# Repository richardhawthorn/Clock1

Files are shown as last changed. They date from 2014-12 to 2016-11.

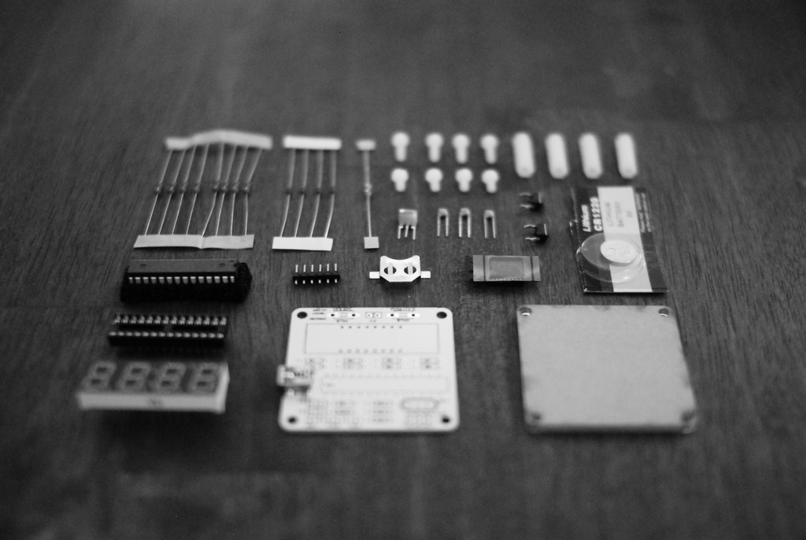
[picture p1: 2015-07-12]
images/parts1.jpg

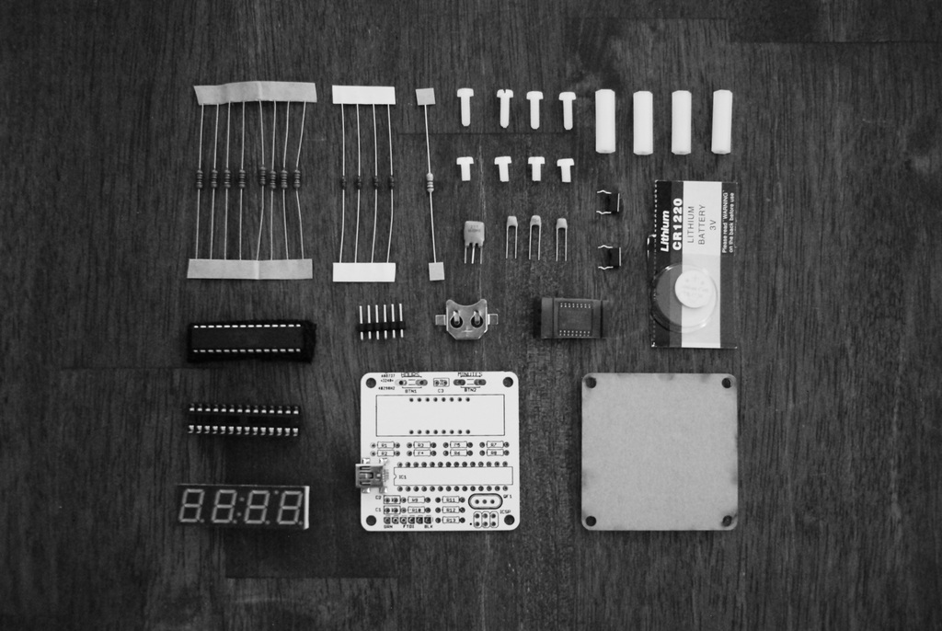
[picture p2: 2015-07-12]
images/parts2.jpg

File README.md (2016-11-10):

### Description

PCB and Arduino code for a basic clock

<div id="link">
	<a href="http://www.deluxecapacitor.com/projects/view/1">Project Page</a>
</div>

### Features

- 4 character 7-segment LED display
- ATMEGA328P with Arduino boot-loader
- 5V operation @ 16Mhz
- DS3231 battery backed clock
- 2x buttons to update minutes and seconds
- Mini USB power connector
- FTDI programming port
- ICSP port

#### Changes

Clock1.1 - First version
Clock1.2 - Replaced surface mount USB connector with through hole version

### License

This work is licensed under a Creative Commons Attribution-ShareAlike 4.0 International License.

<br />
Designed by <a xmlns:cc="http://creativecommons.org/ns#" href="http://www.richardhawthorn.com" property="cc:attributionName" rel="cc:attributionURL" target="_blank">Richard Hawthorn</a><br />
<a rel="license" href="http://creativecommons.org/licenses/by-sa/4.0/" target="_blank">View License</a>

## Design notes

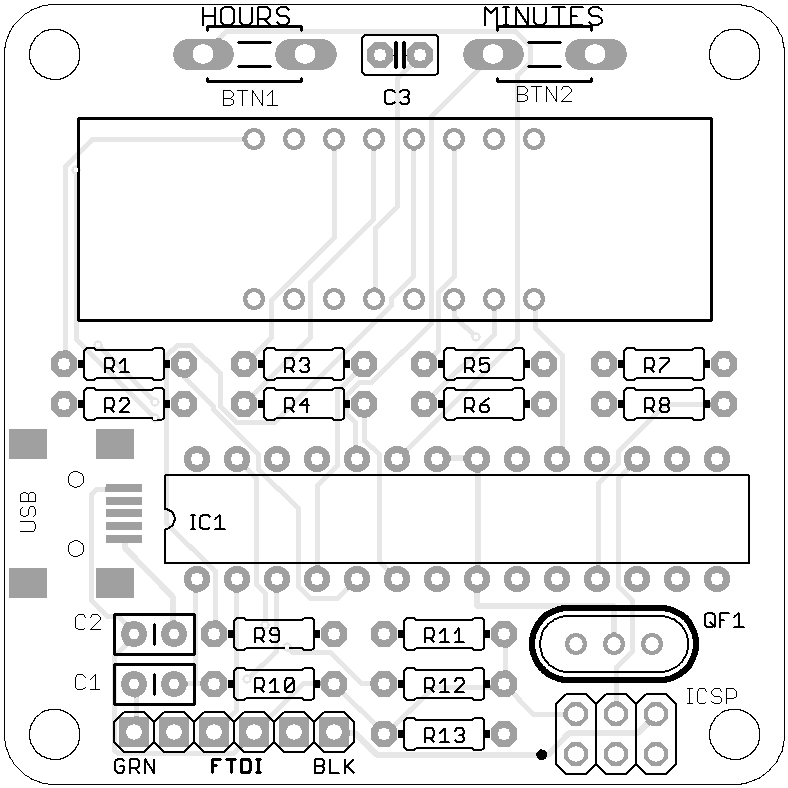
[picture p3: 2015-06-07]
images/pcb_front.png

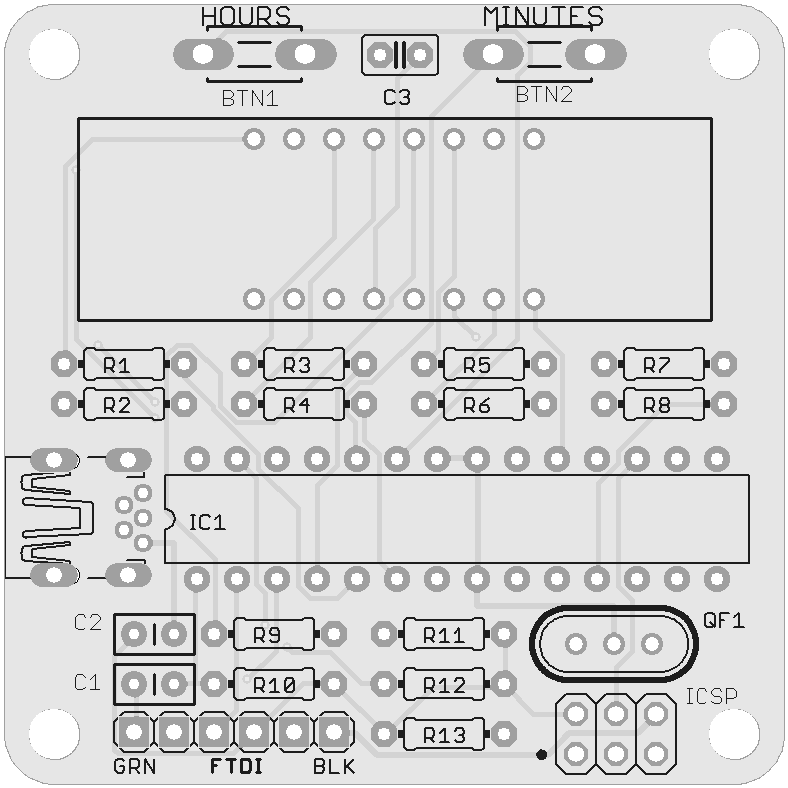
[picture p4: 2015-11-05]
images/pcb_front_1.2.png

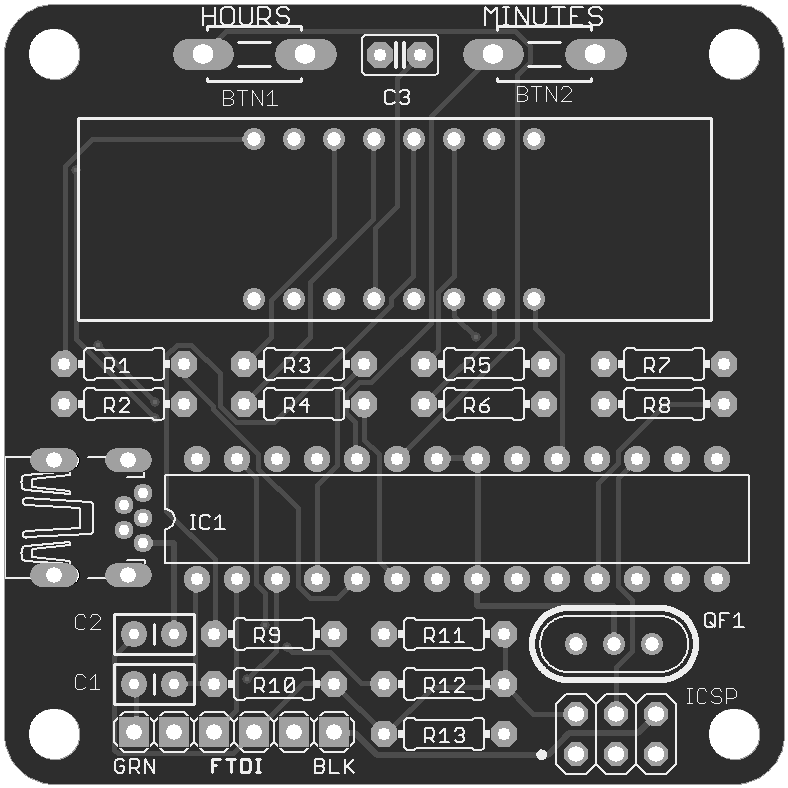
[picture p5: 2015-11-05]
images/pcb_front_1.2_black.png

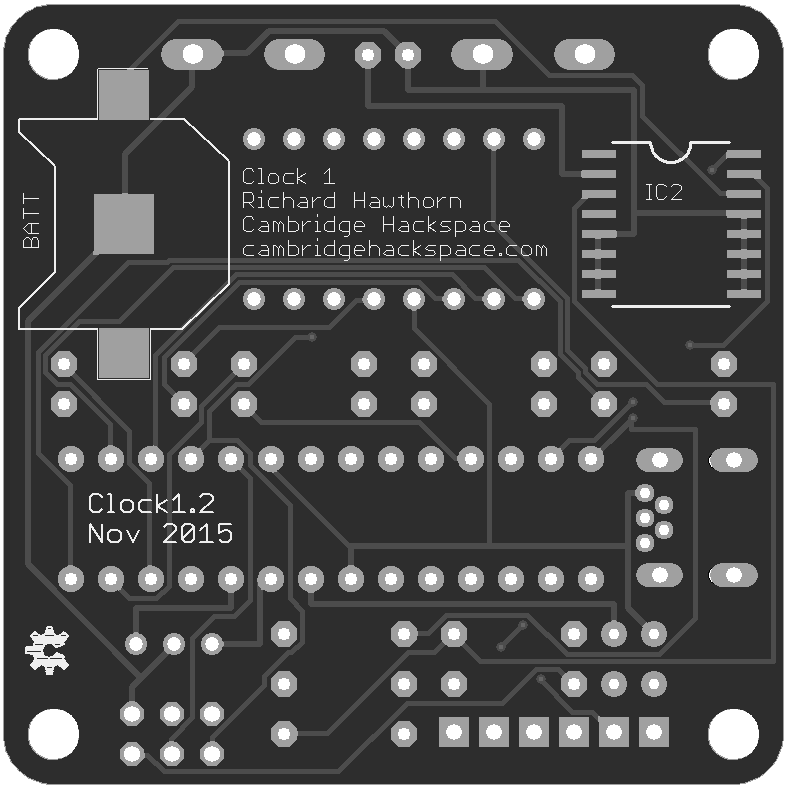
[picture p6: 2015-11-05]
images/pcb_back_1.2_black.png

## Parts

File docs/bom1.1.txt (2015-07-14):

### Part list

<pre>
Qty Value       Device          Parts
3   0.1uf       Capacitor       C1, C2, C3
4   10K         Resistor        R10, R11, R12, R13
1   680r        Resistor        R9
8   82r         Resistor        R1, R2, R3, R4, R5, R6, R7, R8
1   7SEG        7 Segment LED   LED1
1   8M10AHC49T  Crystal         QF1
1   ATMAGE328P  Processor       IC1
1   CR1220      Battery         BATT
1   DS3231      Calendar        IC2 
1   FTDI        Connector-1X6   CN4
1   ICSP        Connector-2X3   ICSP1   (No component needed)
1   HOURS       Button          BTN1
1   MINUTES     Button          BTN2
1   USB         Mini USB        CN1
</pre>

### Additional Hardware

1 x Battery  
1 x IC Socket  
1 x PCB  
1 x Front Plate  
4 x Pillars  
8 x Screws

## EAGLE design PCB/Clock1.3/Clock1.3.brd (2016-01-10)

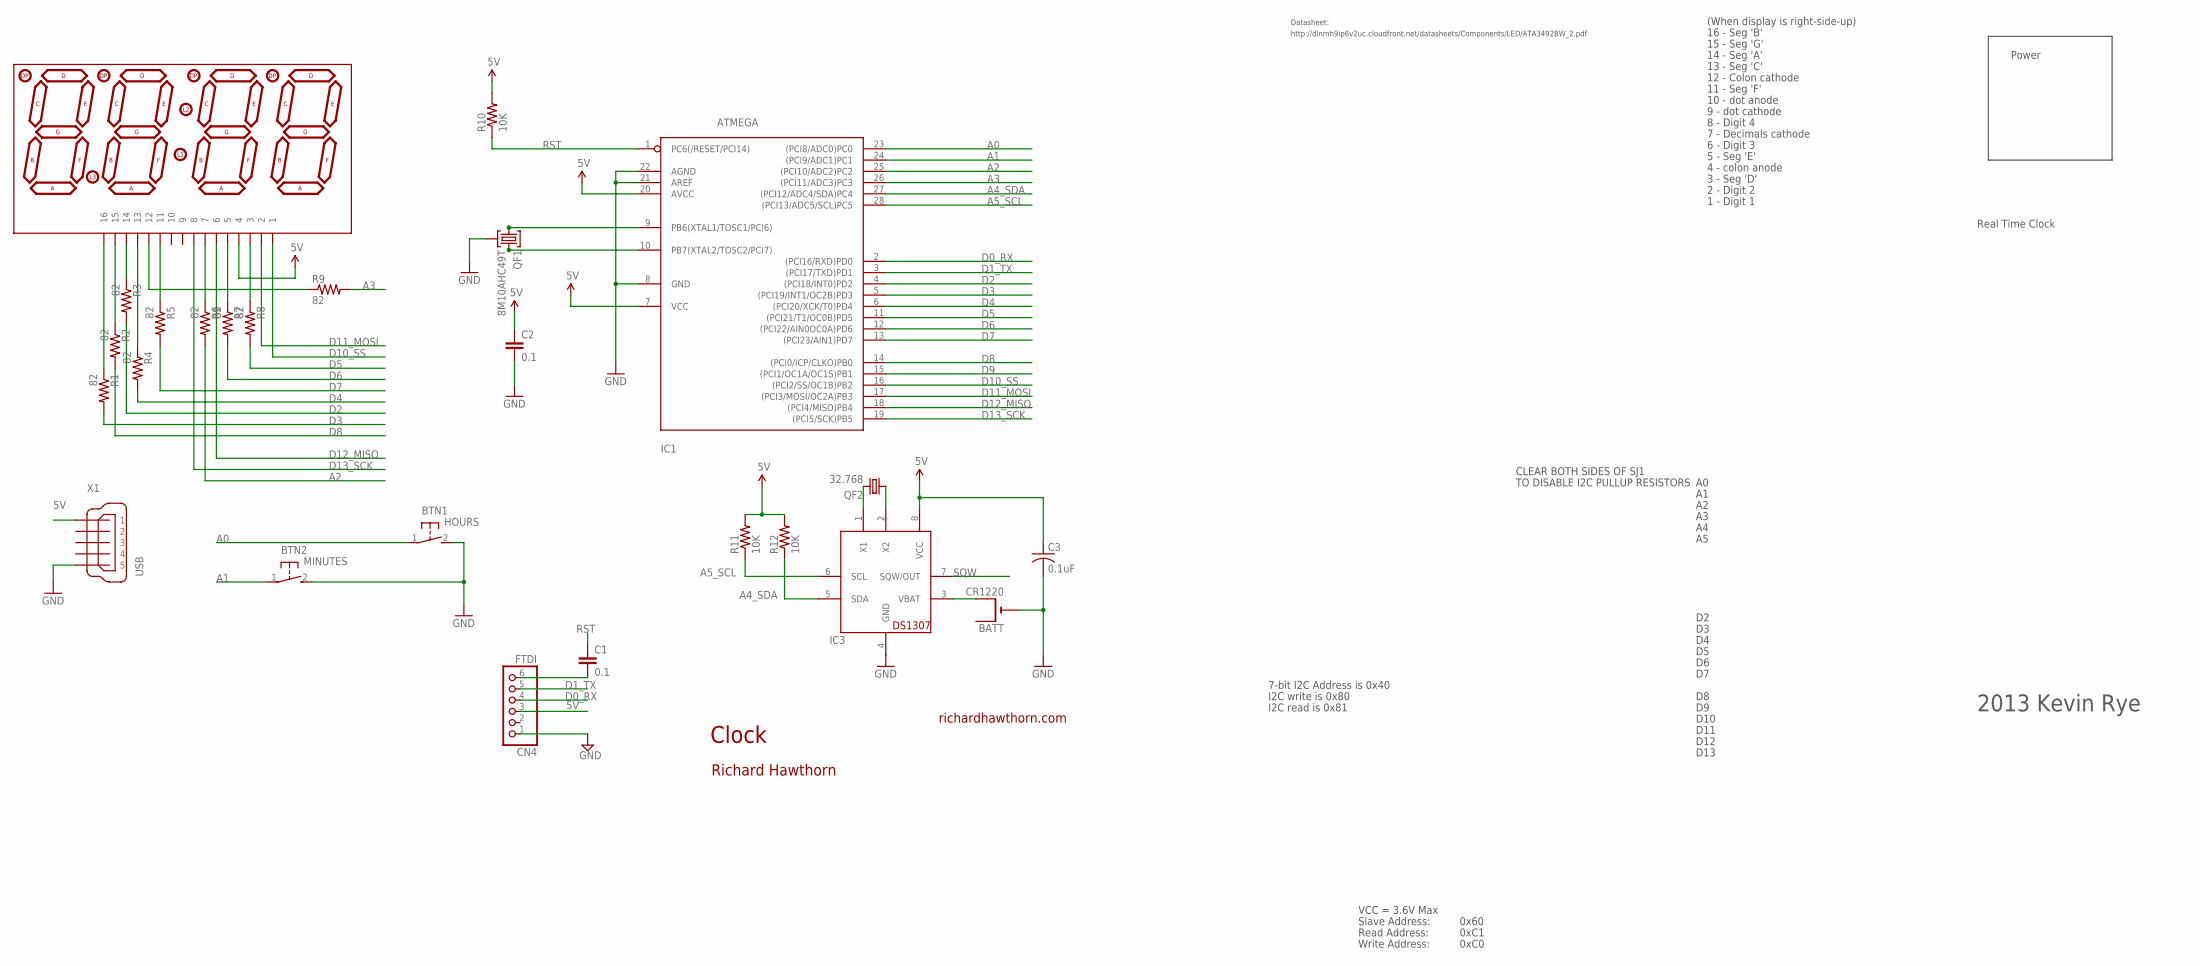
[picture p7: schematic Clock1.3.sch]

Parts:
BATT: CR1220; CR1220-SMD
BTN1: HOURS; DTS-3
BTN2: MINUTES; DTS-3
C1, C2: 0.1; CAP-PTH-SMALL2
C3: 0.1uF; C025-025X050
CN4: FTDI; 1X06
IC1: ATMEGA; DIL28-3-ROUND
IC3: DS1307; DIL08
LED1: 7SEG-4DIGIT; SPARKFUN_7-SEGMENT-4DIGIT
QF1: 8M10AHC49T; HC49U
QF2: 32.768; TC38H
R1, R2, R3, R4, R5, R6, R7, R8, R9: 82; 0204/7
R10, R11, R12: 10K; 0204/7
X1: USB; 32005-601

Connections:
5V: C2.1, C3.1, CN4.3, IC1.7 (VCC), IC1.20 (AVCC), IC3.8 (VCC), LED1.4, R10.2, R11.2, R12.2, X1.1
A0: BTN1.1, IC1.23 ((PCI8/ADC0)PC0)
A1: BTN2.1, IC1.24 ((PCI9/ADC1)PC1)
A2: IC1.25 ((PCI10/ADC2)PC2), R6.2
A3: IC1.26 ((PCI11/ADC3)PC3), R9.2
A4_SDA: IC1.27 ((PCI12/ADC4/SDA)PC4), IC3.5 (SDA), R12.1
A5_SCL: IC1.28 ((PCI13/ADC5/SCL)PC5), IC3.6 (SCL), R11.1
D0_RX: CN4.4, IC1.2 ((PCI16/RXD)PD0)
D1_TX: CN4.5, IC1.3 ((PCI17/TXD)PD1)
D2: IC1.4 ((PCI18/INT0)PD2), R3.2
D3: IC1.5 ((PCI19/INT1/OC2B)PD3), R1.2
D4: IC1.6 ((PCI20/XCK/T0)PD4), R4.2
D5: IC1.11 ((PCI21/T1/OC0B)PD5), R8.2
D6: IC1.12 ((PCI22/AIN0OC0A)PD6), R7.2
D7: IC1.13 ((PCI23/AIN1)PD7), R5.2
D8: IC1.14 ((PCI0/ICP/CLKO)PB0), R2.2
D9: IC1.15 ((PCI1/OC1A/OC1S)PB1)
D10_SS: IC1.16 ((PCI2/SS/OC1B)PB2), LED1.1
D11_MOSI: IC1.17 ((PCI3/MOSI/OC2A)PB3), LED1.2
D12_MISO: IC1.18 ((PCI4/MISO)PB4), LED1.6
D13_SCK: IC1.19 ((PCI5/SCK)PB5), LED1.8
GND: BATT.-, BTN1.2, BTN2.2, C2.2, C3.2, CN4.1, IC1.8 (GND), IC1.21 (AREF), IC1.22 (AGND), IC3.4 (GND), QF1.2, X1.5
unnamed: BATT.+$2 (+1), IC3.3 (VBAT)
unnamed: LED1.16, R1.1
unnamed: LED1.15, R2.1
unnamed: LED1.12, R9.1
unnamed: LED1.7, R6.1
unnamed: IC3.1 (X1), QF2.2
unnamed: IC3.2 (X2), QF2.1
unnamed: IC1.9 (PB6(XTAL1/TOSC1/PCI6)), QF1.1
unnamed: C1.2, CN4.6
unnamed: LED1.13, R4.1
unnamed: LED1.14, R3.1
unnamed: LED1.11, R5.1
unnamed: IC1.10 (PB7(XTAL2/TOSC2/PCI7)), QF1.3
unnamed: LED1.5, R7.1
unnamed: LED1.3, R8.1
RST: C1.1, IC1.1 (PC6(/RESET/PCI14)), R10.1
SQW: IC3.7 (SQW/OUT)

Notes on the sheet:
Clock
richardhawthorn.com
Richard Hawthorn
CLEAR BOTH SIDES OF SJ1
TO DISABLE I2C PULLUP RESISTORS
7-bit I2C Address is 0x40
I2C write is 0x80
I2C read is 0x81
VCC = 3.6V Max
Read Address:
Write Address:
Slave Address:
0x60
0xC1
0xC0
14 - Seg 'A'
13 - Seg 'C'
12 - Colon cathode
11 - Seg 'F'
10 - dot anode
9 - dot cathode
8 - Digit 4
7 - Decimals cathode
6 - Digit 3
5 - Seg 'E'
4 - colon anode
3 - Seg 'D'
2 - Digit 2
Real Time Clock
1 - Digit 1
15 - Seg 'G'
16 - Seg 'B'
D10
D11
D12
D13
http://dlnmh9ip6v2uc.cloudfront.net/datasheets/Components/LED/ATA3492BW_2.pdf
Datasheet:
Power
(When display is right-side-up)

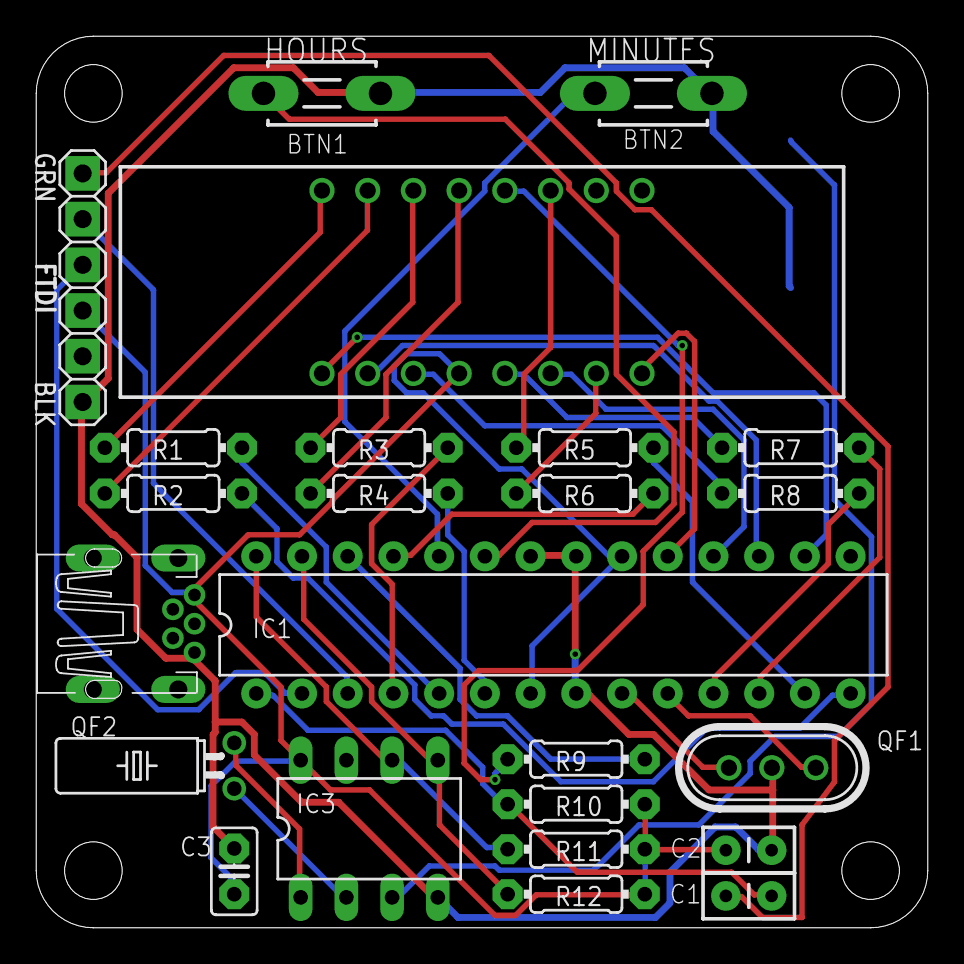
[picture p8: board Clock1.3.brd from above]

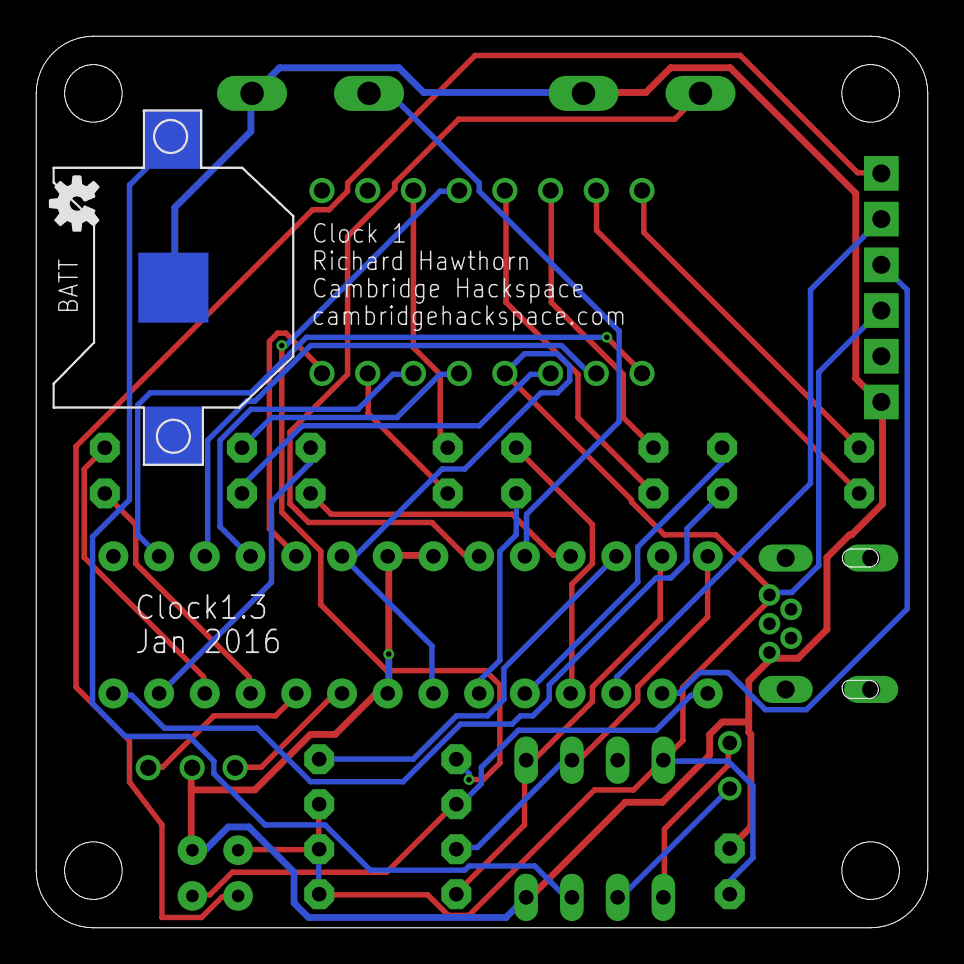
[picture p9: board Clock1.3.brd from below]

Board: 2 copper layers, 49.5 x 49.5 mm, 26 parts (2 on the bottom side), 37 nets.

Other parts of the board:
U$3: OSHW-LOGO-S

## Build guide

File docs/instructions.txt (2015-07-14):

### Instructions

#### Initial components

Lets start building!

- **Resistors:** there are 3 different types  
It doesn’t matter which way around these go.

    82r (grey red black)  
    Part: R1, R2, R3, R4, R5, R6, R7, R8   

    680r (blue grey brown)  
    Part: R9  

    10k (brown black black red)  
    Part: R10, R11, R12, R13    

- **USB connector**  
Part: USB  

- **Buttons**   
Part: BTN1, BTN2  

- **IC socket**  
Part: IC1  
Make sure to match up the notch in the socket with the notch mark on the PCB  
Don’t put in the Arduino chip yet, we’ll do that later.  

- **Capacitors**  
0.1uf  
Part: C1, C2, C3    

- **7 Segment LED**  
Make sure the decimal places are at the bottom  
Part: LED1  

- **Crystal**  
Part: QF1  

- **FTDI** (Programming connector)  
Part: CN4  

#### Testing

Now is a good time to test your soldering (before you have added your Arduino chip).
With your multimeter set to continuity mode, test to make sure you don’t have a short on the power line. Try testing the processor pins 7 and 8, they should not be connected.

If you have a short here, or any other unexpected result during this build you will need to investigate further.  Check your soldering to make sure pins are not shorted together, make sure all solder joins are clean.

Plug in your usb cable, and check the power on the board, do you get 5v between pins 7 and 8 on the processor?

If you read anything less than 5v, unplug immediately.

If that all looks good then we can add in our Arduino chip (Unplug the USB power connector before proceeding). 

Remember to make sure the notch on the end of the processor matches up with the notch on the socket.

#### Final components
- **CR1220 Battery clip**  
Part: BATT   

- **Calendar Chip** - DS3231  
Part: IC2  

Soldering this part requires a steady hand, as it is a surface mount part.  Start by soldering 2 opposite pins of the device, making sure the notch on the chip matches up with the notch on the PCB.

Once you have 2 pins soldered, add some flux to the pins on one side of the chip.  Add solder to the tip of your iron, and touch it on each pin individually.  Do this with every pin on the first side of the chip. Make sure all pins are properly soldered before proceeding, this may mean repeating the soldering as above.

Repeat on the other side of the chip until all pins are soldered.

Note: no component is needed for the ICSP1 connector

#### Final testing

Re-check your soldering by putting the multimeter back into continuity mode, and checking pins 7 and 8 of the processor again.  These should not be shorted.

Power up the board and make sure you get 5v between pins 7 and 8.

If you read anything less than 5v, unplug immediately. 

Investigate your soldering if you see unexpected results.

#### Programming

You are now ready to program your device, grab an FTDI programmer, your usb cable and your laptop.  

Make sure you have downloaded the Arduino IDE from arduino.cc

You will also need the RTC library, follow their install instructions to get the library setup. Details here:
https://github.com/adafruit/RTClib

You may need to restart the Arduino IDE before proceeding

You can now download the clock software here: https://github.com/richardhawthorn/Clock1

When programming set the device as “Arduino UNO” 

#### Front plate

Once you have the software working you can add the front plate.

Remove the plastic from the perspex front plate, and screw it to the pillars.  This can then be attached to the pcbs using the remains screws.

#### Finished!

Da-da! You’ve built yourself an Arduino Clock.  Congratulations!

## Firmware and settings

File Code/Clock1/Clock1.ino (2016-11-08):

//   Clock1.1
//   Richard Hawthorn
//   Cambridge Hackspace
//   Based on code from Kevin Rye
//   2015-05-15
//
//   7 segment led pixels
//
//    _____         __A__
//   |     |       F     B
//   |_____|  -->  |--G--|
//   |     |       E     C
//   |_____|       |__D__|
//
//   Characters
//    _____     _____     _____     _____ 
//   |     |   |     | . |     |   |     |
//   |_____|   |_____|   |_____|   |_____|
//   |     |   |     | . |     |   |     |
//   |_____| o |_____| o |_____| o |_____| o
//      1         2         3         4
//

//includes
#include <Wire.h>
#include <RTClib.h>
RTC_DS1307 RTC;

//define time variables
int hours; //24 hour time
int hh; //12 hour
int mm;
int ss;
int timecc;

//how long to pause between each character
int displayPause = 1;

//define Pins
int segmentD = 5;
int segmentE = 6;
int segmentF = 7;
int segmentA = 2;
int segmentB = 3;
int segmentC = 4;
int segmentG = 8;
int ampm = 9;
int digitOne = 10;
int digitTwo = 11;
int digitThree = 12;
int digitFour = 13;
int hoursButton = A0;
int minsButton = A1;
int decimal = A2;

//colon pin used for clock2.1 variant
int colon = A3;
boolean colonState = false;
long colonCounter = 0;

//setup
void setup() {

  //pin modes
  pinMode(segmentA, OUTPUT);
  pinMode(segmentB, OUTPUT);
  pinMode(segmentC, OUTPUT);
  pinMode(segmentD, OUTPUT);
  pinMode(segmentE, OUTPUT);
  pinMode(segmentF, OUTPUT);
  pinMode(segmentG, OUTPUT);
  pinMode(digitOne, OUTPUT);
  pinMode(decimal, OUTPUT);
  pinMode(digitTwo, OUTPUT);
  pinMode(digitThree, OUTPUT);
  pinMode(digitFour, OUTPUT);
  pinMode(colon, OUTPUT);
  
  //buttons (with pullups)
  pinMode(hoursButton, INPUT_PULLUP);
  pinMode(minsButton, INPUT_PULLUP);
  
  //setup serial line for debugging
  Serial.begin(9600);
  
  //start the i2c and clock
  Wire.begin();
  RTC.begin();  

  if (! RTC.isrunning()) {
    Serial.println("Clock is not running!");
  }
  
  //flash the colon at 1hz
  flashColon();
  
}





//format and display the time
void displayTime(){
  timecc = hh*100+mm;
  showNum(timecc);
}

//get the current time and perform basic checks
void getTime(){
  
  DateTime now = RTC.now(); //time from the clock in 24 hour mode
  hh = hours = now.hour(); //used to check AM/PM status
  mm = now.minute();
  ss = now.second(); 
  
   //Basic time check
  if (hours > 24){
    hours = 0;
  } 
  
  if (mm >= 60){
    mm = 0;
  } 
  
}

//convert the time to 12 hour format
void convert12h(){
  
  if (hours < 1) {
    hh = 12;
  }

  if ((hours > 12) && (hours < 24)) {
    hh = hours - 12;
  }
  
}

//check the buttons, do we need to update the time
void checkButtons(){
  
   //hours button pressed
  if (digitalRead(hoursButton) == LOW) {
    //basic debounce
    delay(200);
    hours++;

    if (hours > 23) {
      hours = 0;
    }
    
    updateRTC();

  } 

  //minutes button pressed
  if (digitalRead(minsButton) == LOW) {
    //basic debounce
    delay(200);

    mm++;
    ss = 0;

    if (mm >59) {
      mm = 0;
    }
    
    updateRTC();

  }
  
}

//display the time
void showNum(int n) {

  //display digit X
  //digit 1 - only display if time is greater thatn 9:59
  int n1 = (n%10000)/1000;
  if (n > 999) {
    printNumber(n1,1);
  }
  delay(displayPause);
  resetNumbers();

  //digit 2
  int n2 = (n%1000)/100;
  printNumber(n2,2); 
  delay(displayPause);
  resetNumbers();

  //digit 3
  int n3 = (n%100)/10;
  printNumber(n3,3);
  delay(displayPause);
  resetNumbers();

  //digit 4
  int n4 = n%10;
  printNumber(n4,4); 
  delay(displayPause);
  resetNumbers();

}

//reset the screen, so everything is off
void resetNumbers(){
  
    digitalWrite(digitOne,LOW);
    digitalWrite(digitTwo,LOW);
    digitalWrite(digitThree,LOW);
    digitalWrite(digitFour,LOW);
    digitalWrite(decimal,HIGH); //decimal off
    digitalWrite(segmentA,HIGH);
    digitalWrite(segmentB,HIGH);
    digitalWrite(segmentC,HIGH);
    digitalWrite(segmentD,HIGH);
    digitalWrite(segmentE,HIGH);
    digitalWrite(segmentF,HIGH);
    digitalWrite(segmentG,HIGH);  
  
}

//output a specific number in a specific position
//n = number, d = position
void printNumber(int n, int d) {
 
  if ((n > 9) || (n < 0)){
    return;  
  }
  
  if ((d > 4) || (d < 1)){
    return;  
  }
  
  //d is the display to illuminate
  if(d==1)  {
    digitalWrite(digitOne,HIGH);
    digitalWrite(digitTwo,LOW);
    digitalWrite(digitThree,LOW);
    digitalWrite(digitFour,LOW);
    digitalWrite(decimal,HIGH); //decimal off
  } 

  if(d==2) {
    digitalWrite(digitOne,LOW);
    digitalWrite(digitTwo,HIGH);
    digitalWrite(digitThree, LOW);
    digitalWrite(digitFour,LOW);
    digitalWrite(decimal,HIGH); //decimal off
  }

  if(d==3) {
    digitalWrite(digitOne,LOW);
    digitalWrite(digitTwo,LOW);
    digitalWrite(digitThree,HIGH);
    digitalWrite(digitFour,LOW);
    digitalWrite(decimal,HIGH); //decimal off
  }

  if(d==4) {
    digitalWrite(digitOne,LOW);
    digitalWrite(digitTwo,LOW);
    digitalWrite(digitThree,LOW);
    digitalWrite(digitFour,HIGH);
    digitalWrite(decimal,HIGH); //decimal off
  }
 
  //n is for the number to be displayed
  switch(n) {
  case 0:
    digitalWrite(segmentA,LOW);
    digitalWrite(segmentB,LOW);
    digitalWrite(segmentC,LOW);
    digitalWrite(segmentD,LOW);
    digitalWrite(segmentE,LOW);
    digitalWrite(segmentF,LOW);
    digitalWrite(segmentG,HIGH);
    break;
    

  case 1:
    digitalWrite(segmentA,HIGH);
    digitalWrite(segmentB,LOW);
    digitalWrite(segmentC,LOW);
    digitalWrite(segmentD,HIGH);
    digitalWrite(segmentE,HIGH);
    digitalWrite(segmentF,HIGH);
    digitalWrite(segmentG,HIGH);
    break;

  case 2:
    digitalWrite(segmentA,LOW);
    digitalWrite(segmentB,LOW);
    digitalWrite(segmentC,HIGH);
    digitalWrite(segmentD,LOW);
    digitalWrite(segmentE,LOW);
    digitalWrite(segmentF,HIGH);
    digitalWrite(segmentG,LOW);
    break;

  case 3:
    digitalWrite(segmentA,LOW);
    digitalWrite(segmentB,LOW);
    digitalWrite(segmentC,LOW);
    digitalWrite(segmentD,LOW);
    digitalWrite(segmentE,HIGH);
    digitalWrite(segmentF,HIGH);
    digitalWrite(segmentG,LOW);
    break;

  case 4:
    digitalWrite(segmentA,HIGH);
    digitalWrite(segmentB,LOW);
    digitalWrite(segmentC,LOW);
    digitalWrite(segmentD,HIGH);
    digitalWrite(segmentE,HIGH);
    digitalWrite(segmentF,LOW);
    digitalWrite(segmentG,LOW);
    break;

  case 5:
    digitalWrite(segmentA,LOW);
    digitalWrite(segmentB,HIGH);
    digitalWrite(segmentC,LOW);
    digitalWrite(segmentD,LOW);
    digitalWrite(segmentE,HIGH);
    digitalWrite(segmentF,LOW);
    digitalWrite(segmentG,LOW);
    break;

  case 6:
    digitalWrite(segmentA,LOW);
    digitalWrite(segmentB,HIGH);
    digitalWrite(segmentC,LOW);
    digitalWrite(segmentD,LOW);
    digitalWrite(segmentE,LOW);
    digitalWrite(segmentF,LOW);
    digitalWrite(segmentG,LOW);
    break;

  case 7:
    digitalWrite(segmentA,LOW);
    digitalWrite(segmentB,LOW);
    digitalWrite(segmentC,LOW);
    digitalWrite(segmentD,HIGH);
    digitalWrite(segmentE,HIGH);
    digitalWrite(segmentF,HIGH);
    digitalWrite(segmentG,HIGH);
    break;

  case 8:
    digitalWrite(segmentA,LOW);
    digitalWrite(segmentB,LOW);
    digitalWrite(segmentC,LOW);
    digitalWrite(segmentD,LOW);
    digitalWrite(segmentE,LOW);
    digitalWrite(segmentF,LOW);
    digitalWrite(segmentG,LOW);
    break;

  case 9:
    digitalWrite(segmentA,LOW);
    digitalWrite(segmentB,LOW);
    digitalWrite(segmentC,LOW);
    digitalWrite(segmentD,LOW);
    digitalWrite(segmentE,HIGH);
    digitalWrite(segmentF,LOW);
    digitalWrite(segmentG,LOW);
    break;
  }
}

//tell the clock to flash the colon
void flashColon(){
  
  //set SQW on clock to 1 hz for flashing colon
  Wire.beginTransmission(104);
  Wire.write(0x0E); // point to SQW address
  Wire.write(0b00000000); // send 1Hz
  Wire.endTransmission();
  
}

//convert decimal number to binary
byte decToBcd(byte val) {
  return ( (val/10*16) + (val%10) );
}

//convert binary number to decimal
byte bcdToDec(byte val) {
  return ( (val/16*10) + (val%16) );
}

//update the clock with the updated time
void updateRTC() {
  Wire.beginTransmission(104);
  Wire.write(0);
  Wire.write(decToBcd(ss));
  Wire.write(decToBcd(mm));
  Wire.write(decToBcd(hours));
  Wire.endTransmission();
}

void checkColon(){

  //code used to flash the colon on the v2.1 variant
  colonCounter++;

  if (colonCounter > 86){
    colonCounter = 0;
    if (colonState){
      colonState = false;
      digitalWrite(colon,HIGH);
    } else {
      colonState = true;
      digitalWrite(colon,LOW);
    }
  }
  
}



//main loop
void loop() {
 
  getTime();
  //convert12h();
  displayTime();
  checkButtons();
  checkColon();
  
}

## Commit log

2014-12-05 Added pcb
    [Clock1.1.brd, Clock1.1.sch]
2015-06-07 added Arduino code
2015-06-07 add pcb images
2015-07-11 added instructions and bom
2015-07-14 update bom
2015-07-15 update to Arduino code
2015-11-05 update to version 1.2
    [Clock1.2.brd, Clock1.2.sch]
2015-11-05 added gerbers for clock1.2
2016-01-10 initial design for v1.3
    [Clock1.3.brd, Clock1.3.sch]
2016-11-08 update to schematic
    [Clock1.2.sch]
2016-11-08 updated readme and added bom

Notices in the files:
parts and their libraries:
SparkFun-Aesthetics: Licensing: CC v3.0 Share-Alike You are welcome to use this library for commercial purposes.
